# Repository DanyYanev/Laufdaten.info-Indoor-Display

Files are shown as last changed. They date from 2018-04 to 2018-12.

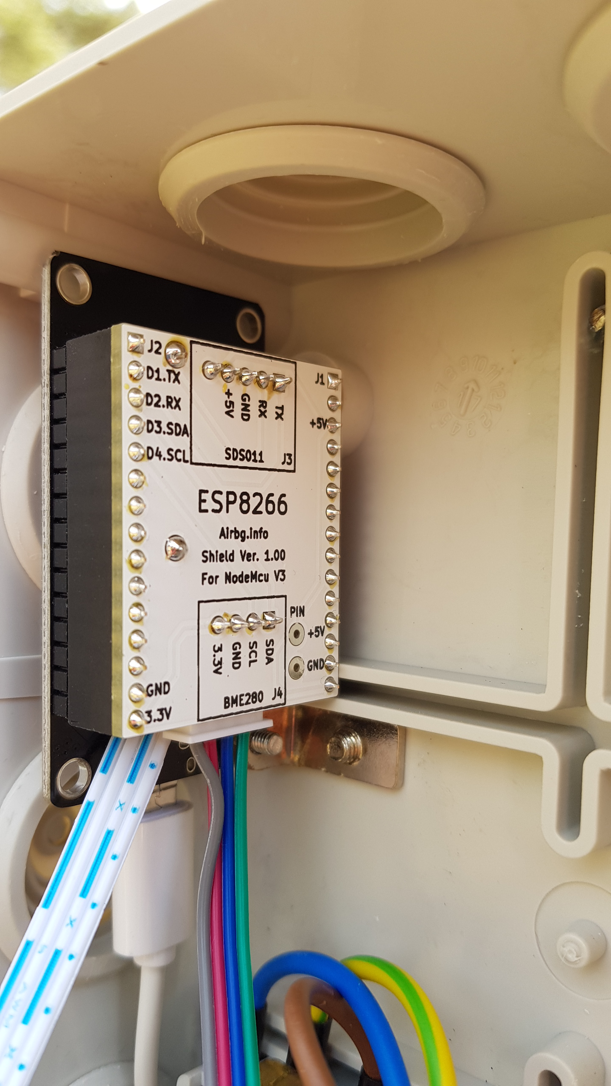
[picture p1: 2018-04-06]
shields/Outdoor Sensor Shield/Pictures/20180310_093059.jpg

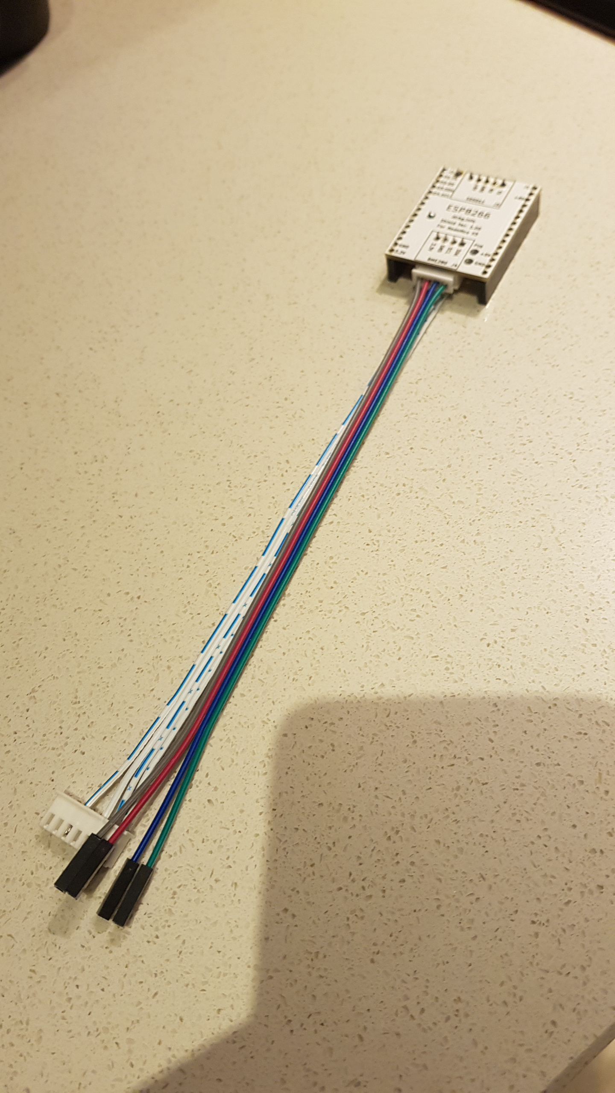
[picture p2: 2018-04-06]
shields/Outdoor Sensor Shield/Pictures/20180309_204822.jpg

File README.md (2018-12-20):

# Laufdaten.info Dust Sensor Indoor Display
Add-on indoor display for your [**laufdaten dust sensor**](https://luftdaten.info/en/home-en/)

If you are contributing to the [**luftdaten.info**](https://luftdaten.info/en/home-en/) project you can build your own indoor weather station and fetch the data off your outdoor sensor.
# How it works
Outside sensor sends information to the Laufdaten servers and to the indoor controller API that displays it on display by your choice. The display controller is connected to your local network with static IP configured from the .ino file (default 192.168.0.50).
The same IP Address you have to add in the outside sensor to send data to the indoor display controller. (More on that in the Configuration Tab) 

*Screenshots from 2.8"(background actually is black)*
allpages

# Getting Started
You will need:
  - Working [Laufdaten dust sensor](https://luftdaten.info/en/construction-manual/) **with BME 280 and SDS011**
  - *Another* NodeMCU v3 ESP8266 or ESP-12E
  - *Another* BME 280
  - A display
    - OLED 0.96" I2C interface
    - OLED 1.3" I2C interface
    - LCD TFT 1.44" SPI interface
    - LCD TFT 2.8"  SPI interface with touch
    - LCD TFT 2.8"  SPI interface without touch
    
## Installing
  ##### Setting up the arduino IDE
  - Install the [Arduino IDE](https://www.arduino.cc/en/Main/Software)
  - Add ESP8266 Libraries
    To begin, we’ll need to update the board manager with a custom URL. Open up Arduino, then go to the Preferences (File > Preferences).       Then, towards the bottom of the window, copy this URL into the “Additional Board Manager URLs” text box:

     > http://arduino.esp8266.com/stable/package_esp8266com_index.json
   - Install the following libraries
      - [WifiManager by Ken Taylor](https://github.com/kentaylor/WiFiManager)
      - [Adafruit Sensors](https://github.com/adafruit/Adafruit_Sensor)
      - [Adafruit BME280](https://github.com/adafruit/Adafruit_BME280_Library)
      - LCD
        - [TFT_eSPI by Bodmer](https://github.com/Bodmer/TFT_eSPI)
      - OLED
        - [Driver library for the SSD1306 and SH1106 OLED by ThingPulse](https://github.com/ThingPulse/esp8266-oled-ssd1306)
        
  ##### Connect the hardware for Oled and LCD 1.44"
  - BME280 (I2C)
    - SDA -> D1
    - SDL -> D2
  - OLED (I2C)
    - SDA -> D1
    - SDL -> D2
  - LCD (SPI)
    - TFT_CS -> D8
    - TFT_DC -> D0
    - TFT_RST -> Reset pin
    - TFT_SCL -> D5
    - TFT_SDA -> D7
    - TFT_LED -> +3.3v
    - Make the appropriate changes to User_Setup.h in Bodmer library (by default on Windowns located in Documents/Arduino/libraries/TFT-eSPI/) according to your display. The User_Setup.h file is very well documented.
    - You can find ready User_Setup.h in code folders. For 1.44 if you have screen offset choose different board.
            
  - Buttons (Pin to GND)
    - D6 (Display page changing)
    - D3 (Configuration Mode -Onboard flash button)
  - You can look also schematic pdf in shields folder
  
  ##### Connect the hardware for LCD 2.80"
  - See schematic pdf in shields folder
  
##### Configure the Indoor Display Conroller
  - After uploading the code the controller will run in Configuration Mode automatically. To manually put the controller in config mode use the flash button. 
  - The device tries to connect to the configured WLAN access point. If this does not work, the controller opens an access point with the name "ESP *id*". The ID referes to the ChipID (ex. ESP12345). Connect to the new network, wait a moment until the connection is made. Sometimes it take multiple attempts.
  - Configure using browser
    - Open your browser and type in http://192.168.4.1/. You see the menu site, choose “Configure” and input your credentional.
    - After saving the desired configuration click on **EXIT PORTAL**! Else the configuration won't be saved.
  **OR**
  - Configure using android application. Special thanks to Keneth Taylor.
    - Download the [ESP Connect app](https://play.google.com/store/apps/details?id=au.com.umranium.espconnect) and follow the steps.
  - Oled version is without WiFi menager and you must add wifi SSID and Password in the code.  
  
##### Configure the OutsideSensor
  - Find laufdatens sensor IP Address.
  - Go to its IP Address (ex. 192.168.0.112)
  - Click on Configuration
  - Add the static IP of the indoor display controller 192.168.0.50, (standart router settings from 192.168.0.2 through 192.168.0.99 are not used for DHCP).
  - The path and the port as shown below.
outdoor sensor settings

## Shields
  - Kicad and Gerber files are in shields folder.
    - Indoor display
      - Oled 0.96 (Tested)
      - LCD 1.44  (Tested)
      - LCD 2.80  (ESP-12E tested)
      - LCD 2.80  (NodeMCU not tested)
    - Outdoor sensor for better connection between sensors and ESP.

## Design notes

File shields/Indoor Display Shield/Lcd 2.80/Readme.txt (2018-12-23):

Buttons on D2 and D6 are not used with touchscreen.
Led on D4 duplicate led on ESP.
PCB can be use with another sensors for air quality BME680 or CCS811.

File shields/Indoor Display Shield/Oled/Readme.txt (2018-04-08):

This shield is for Oled 0.96 and few sensors 
(BME280,BME680 and SDS011).
For this code use only BME280 and 2 buttons.

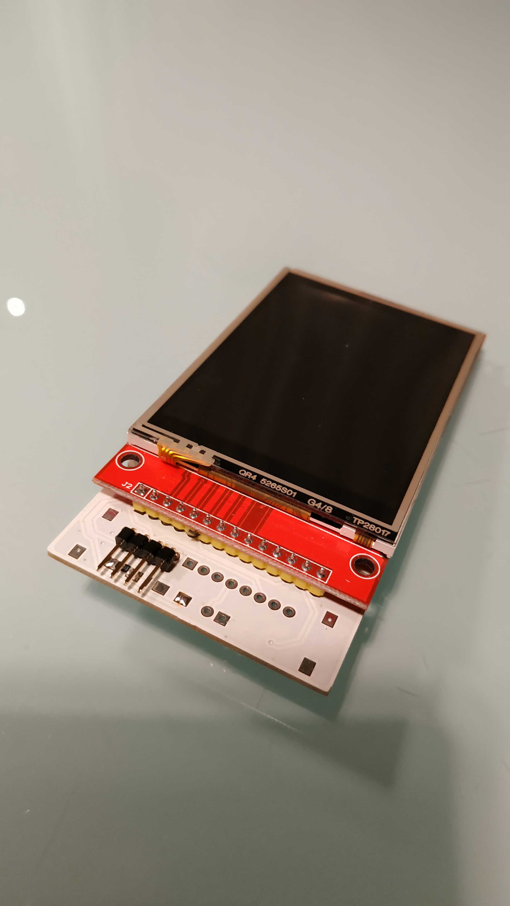
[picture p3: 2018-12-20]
shields/Indoor Display Shield/Lcd 2.80/Pictures ESP-12E/Touch screen1.jpg

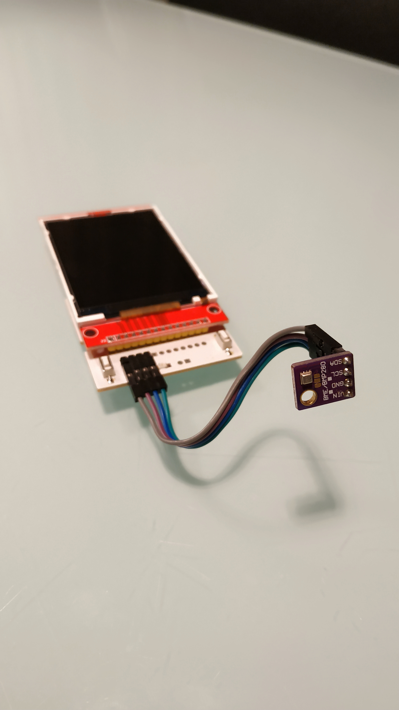
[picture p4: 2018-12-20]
shields/Indoor Display Shield/Lcd 2.80/Pictures ESP-12E/Two buttons4.jpg

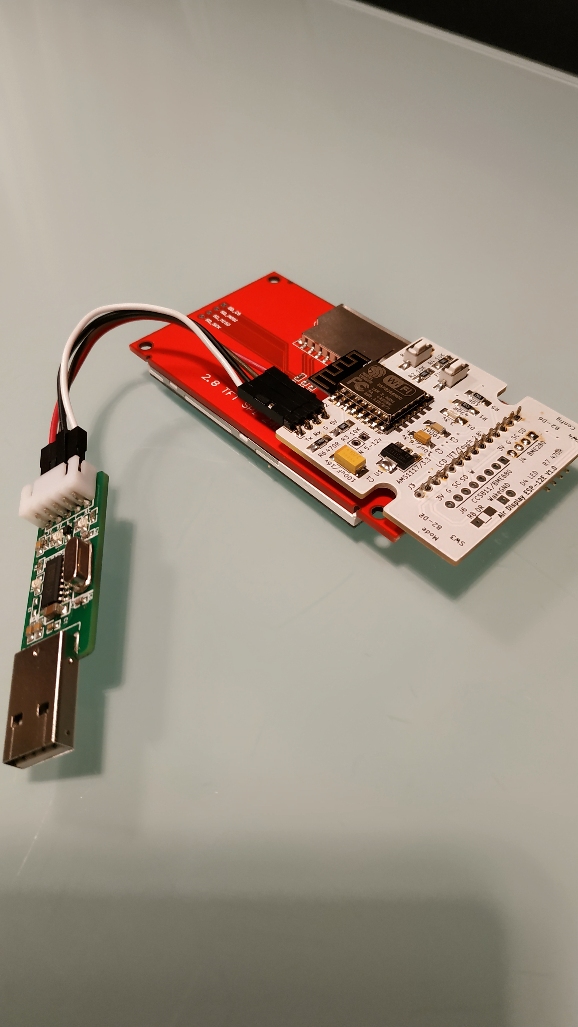
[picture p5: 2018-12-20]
shields/Indoor Display Shield/Lcd 2.80/Pictures ESP-12E/Touch screen3.jpg

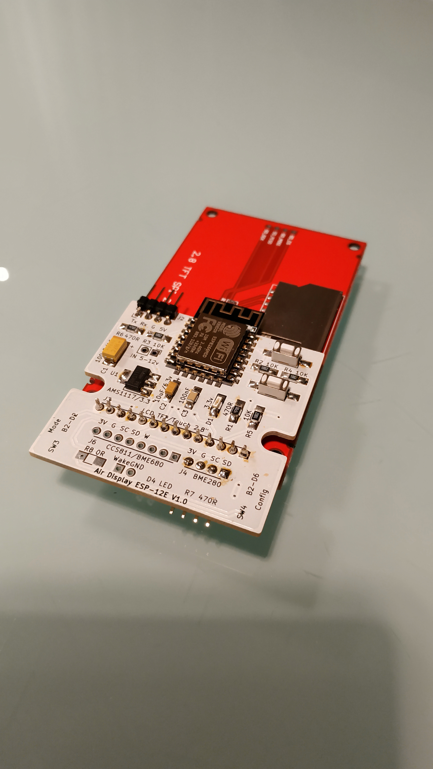
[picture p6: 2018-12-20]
shields/Indoor Display Shield/Lcd 2.80/Pictures ESP-12E/Touch screen2.jpg

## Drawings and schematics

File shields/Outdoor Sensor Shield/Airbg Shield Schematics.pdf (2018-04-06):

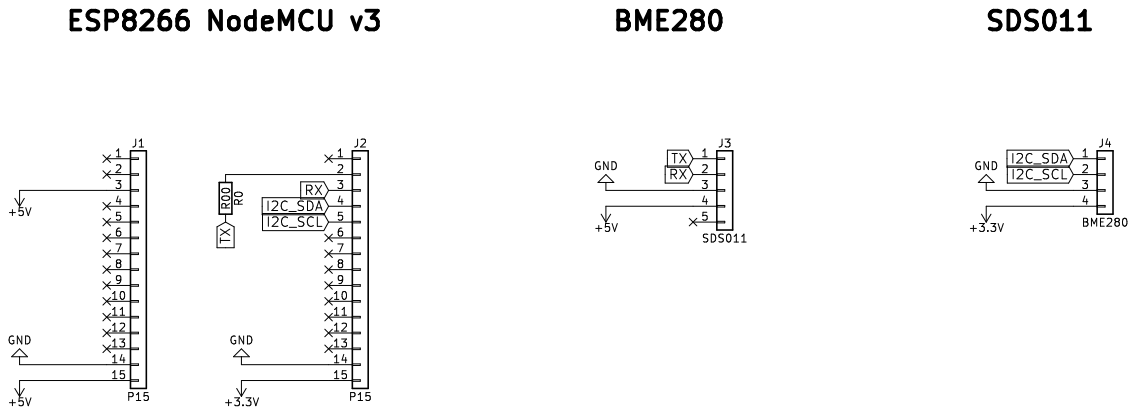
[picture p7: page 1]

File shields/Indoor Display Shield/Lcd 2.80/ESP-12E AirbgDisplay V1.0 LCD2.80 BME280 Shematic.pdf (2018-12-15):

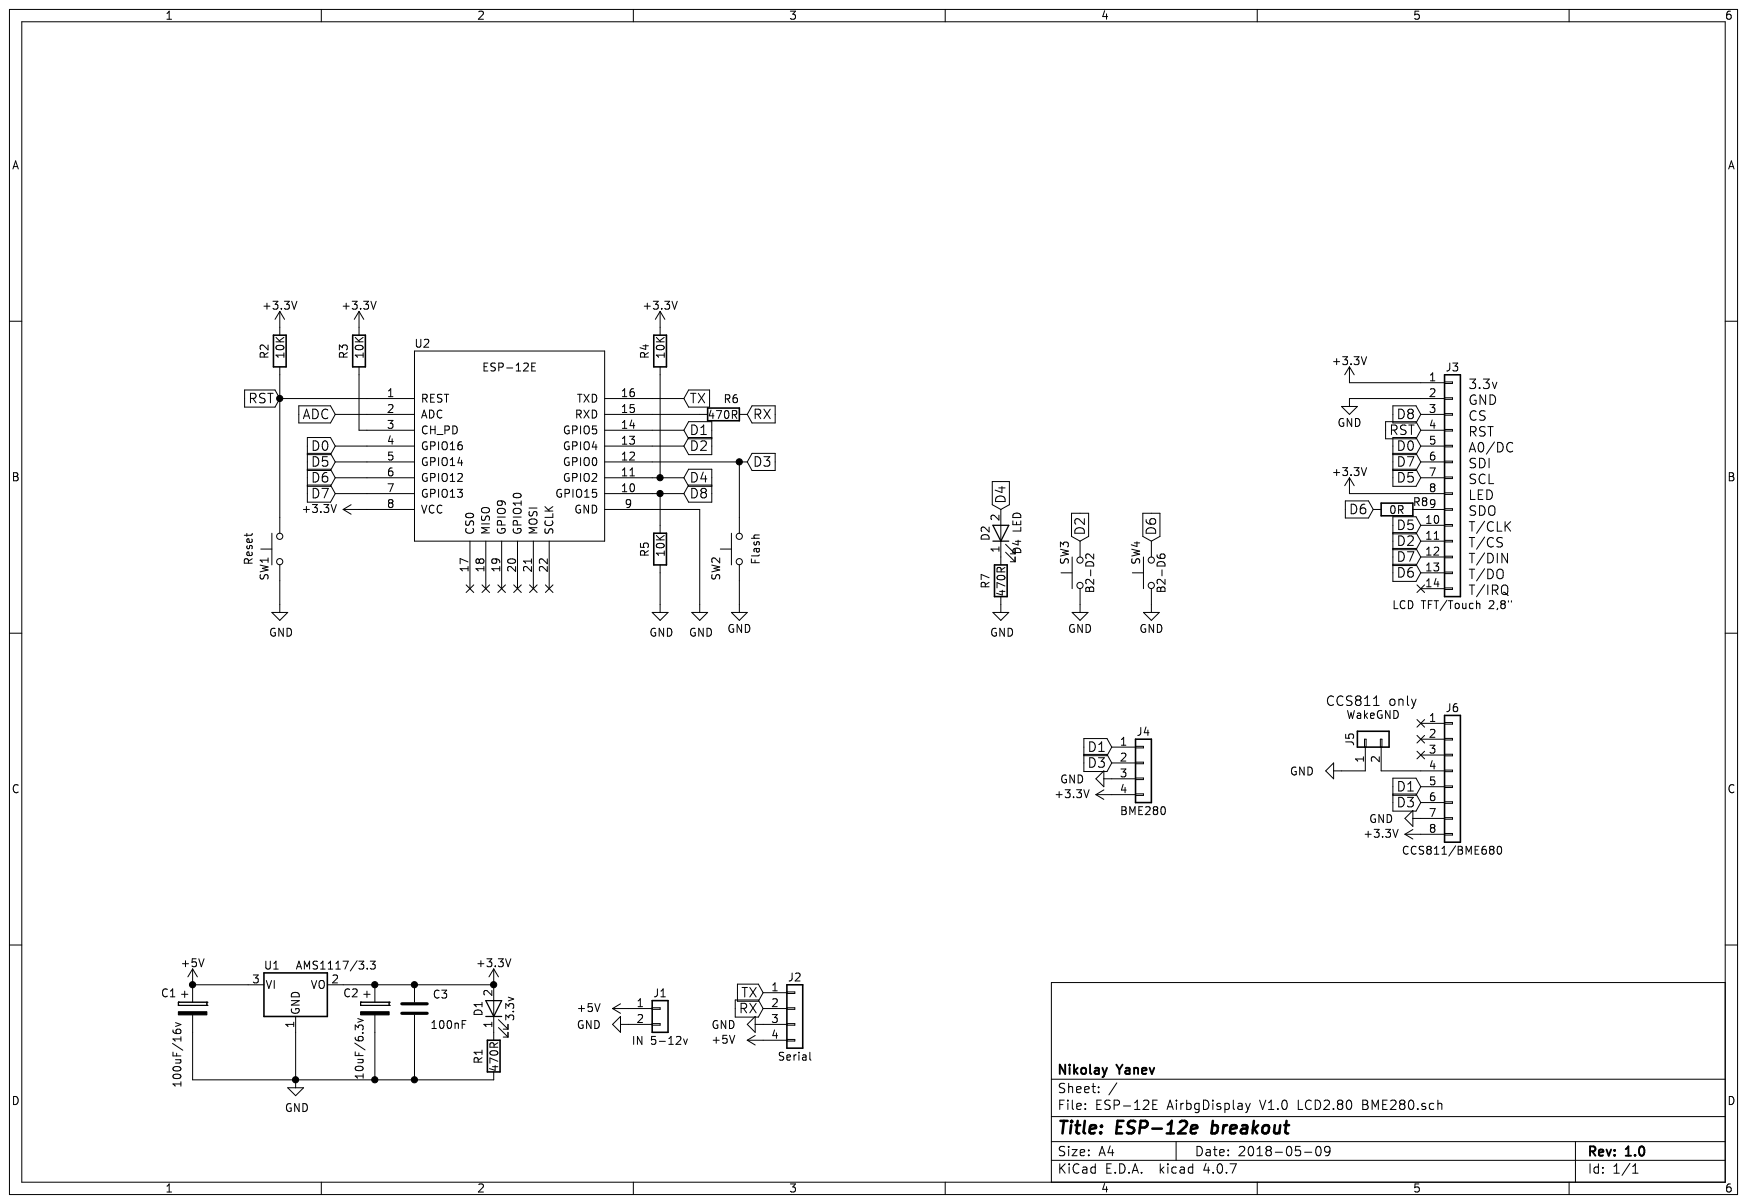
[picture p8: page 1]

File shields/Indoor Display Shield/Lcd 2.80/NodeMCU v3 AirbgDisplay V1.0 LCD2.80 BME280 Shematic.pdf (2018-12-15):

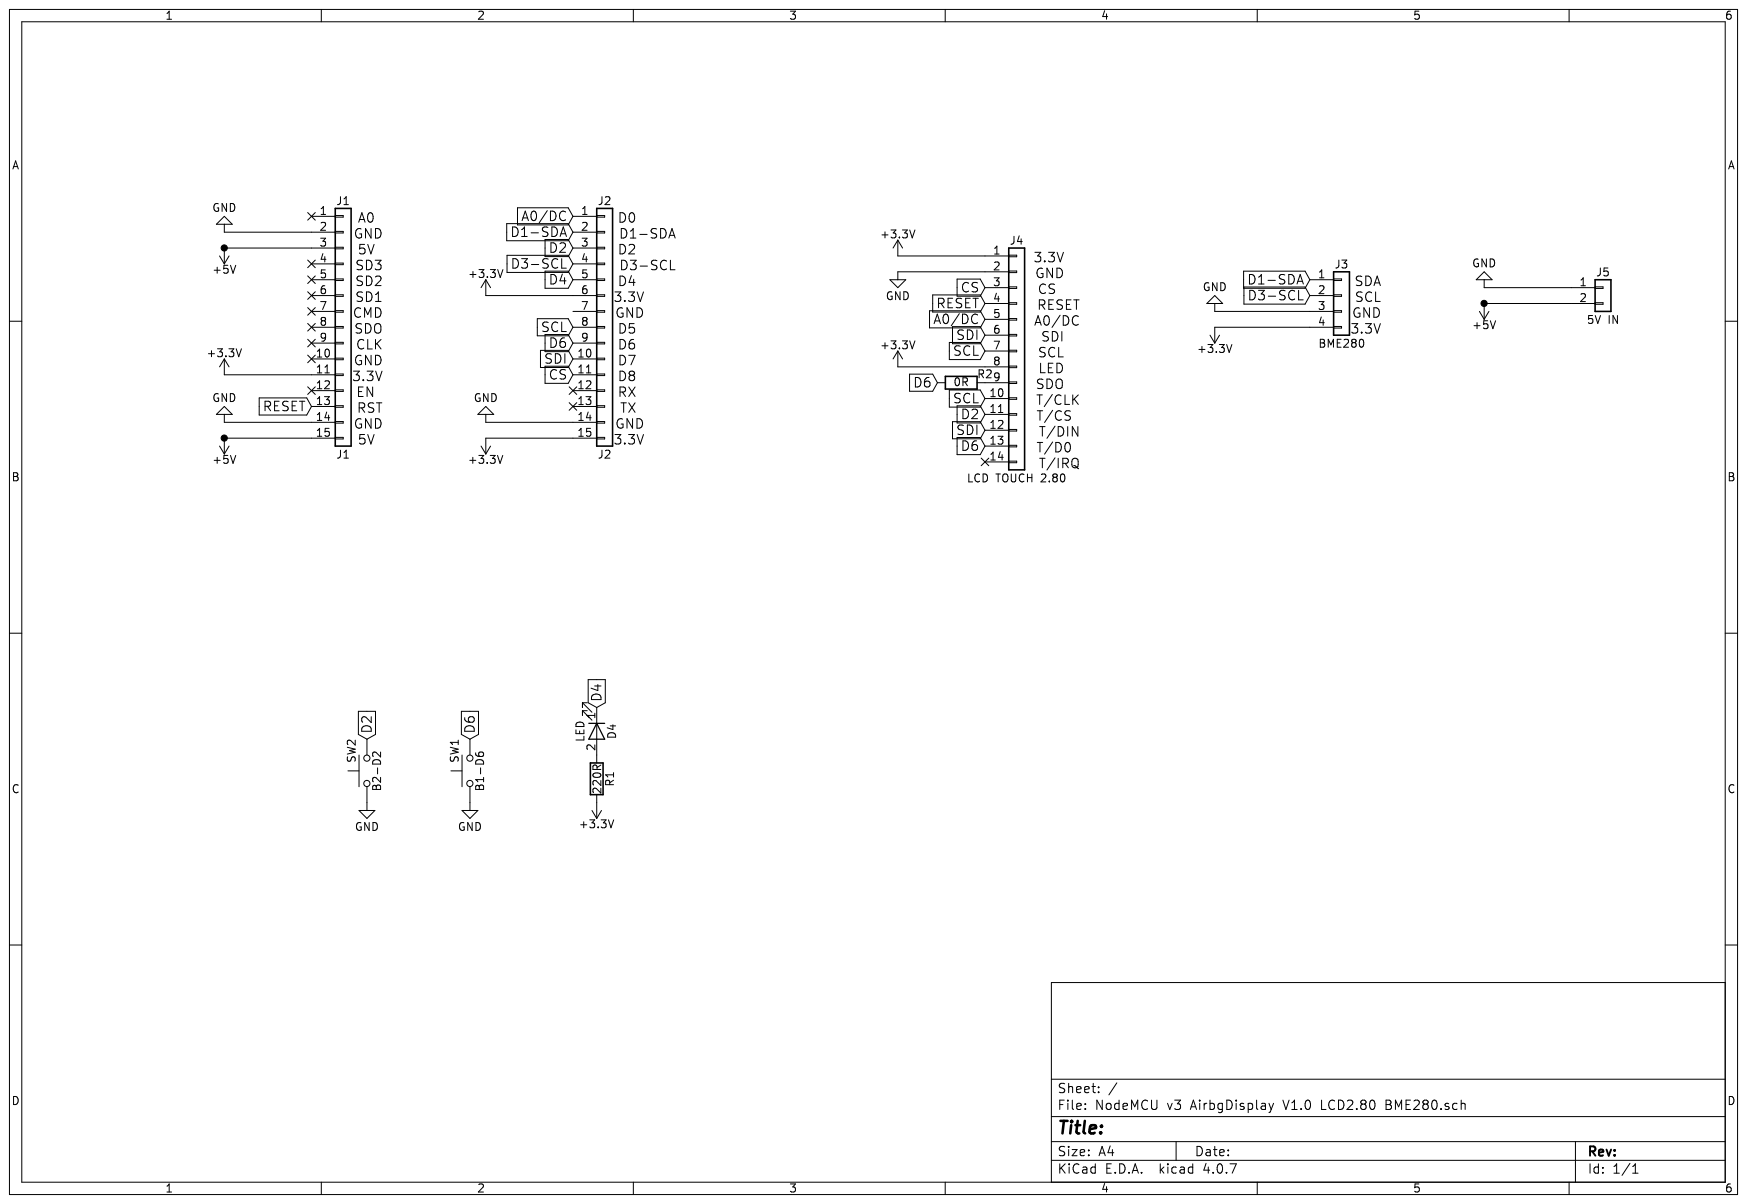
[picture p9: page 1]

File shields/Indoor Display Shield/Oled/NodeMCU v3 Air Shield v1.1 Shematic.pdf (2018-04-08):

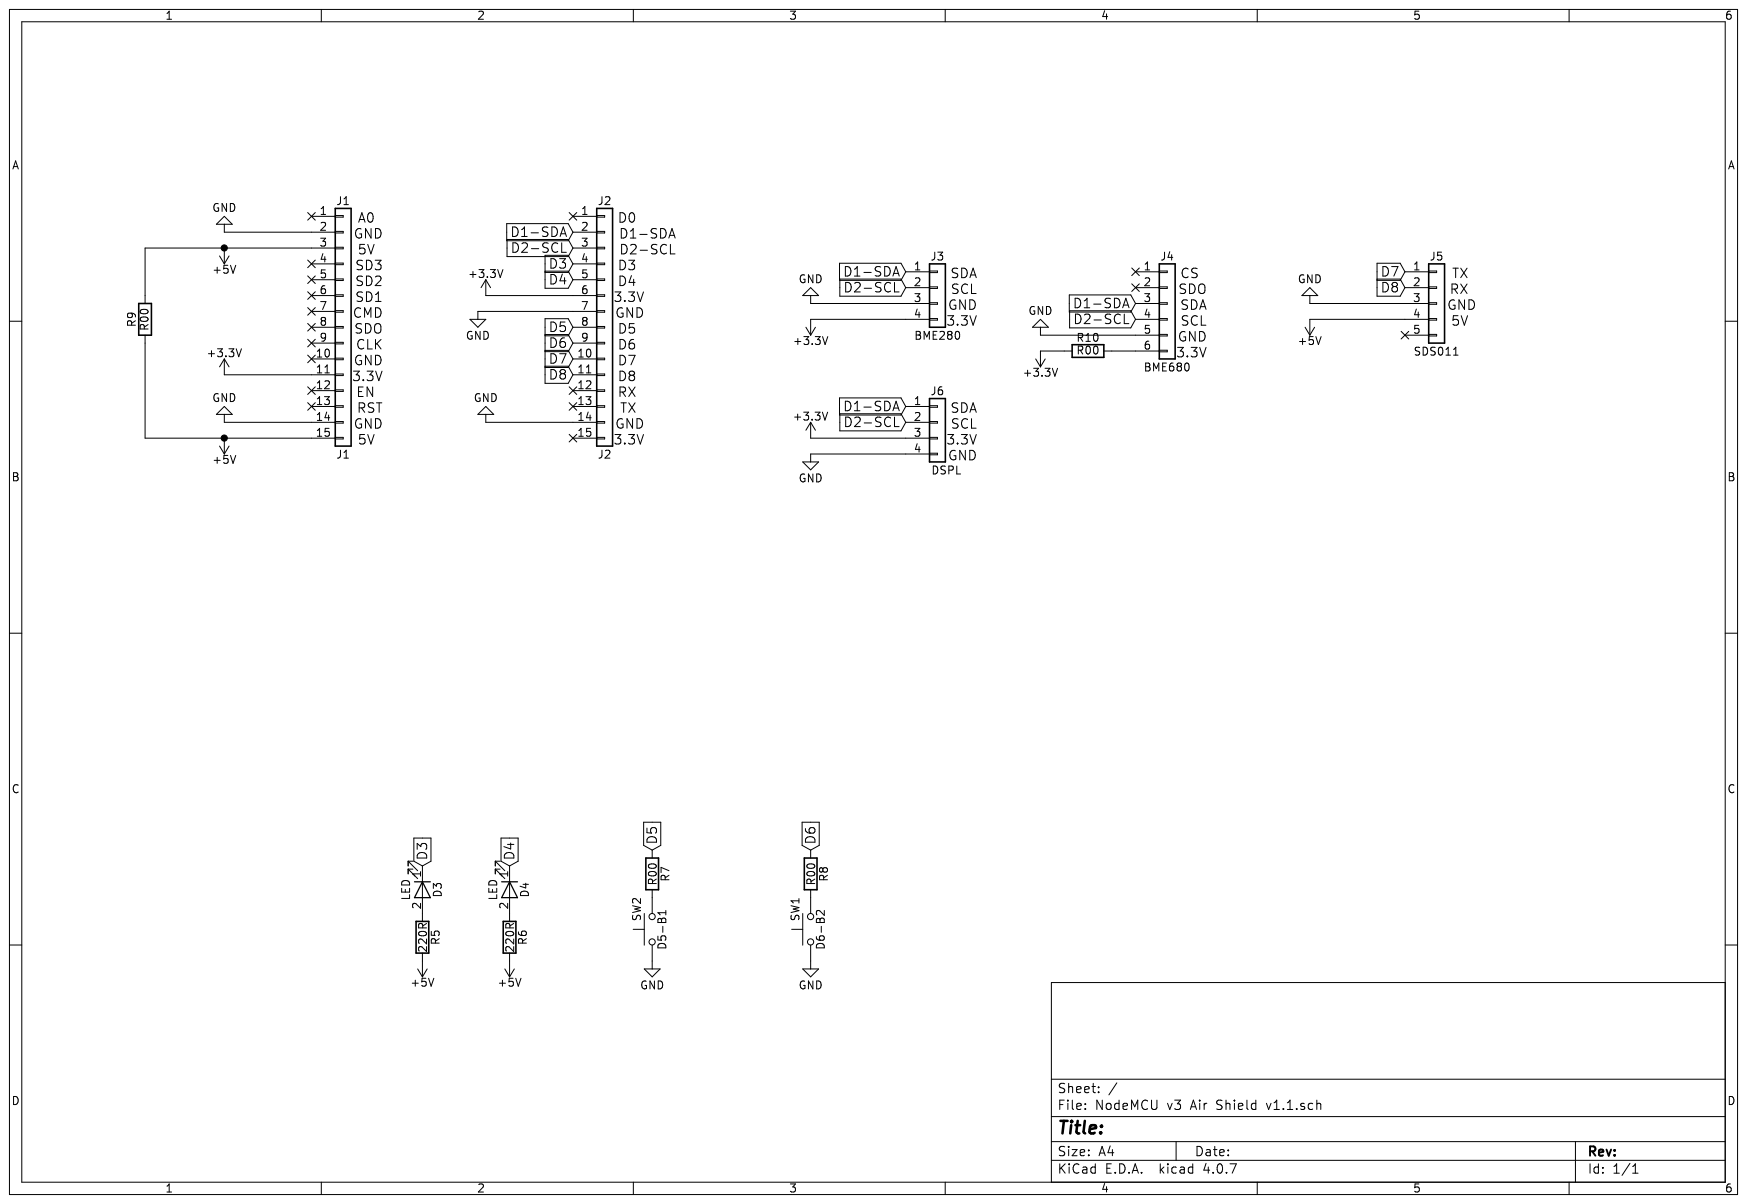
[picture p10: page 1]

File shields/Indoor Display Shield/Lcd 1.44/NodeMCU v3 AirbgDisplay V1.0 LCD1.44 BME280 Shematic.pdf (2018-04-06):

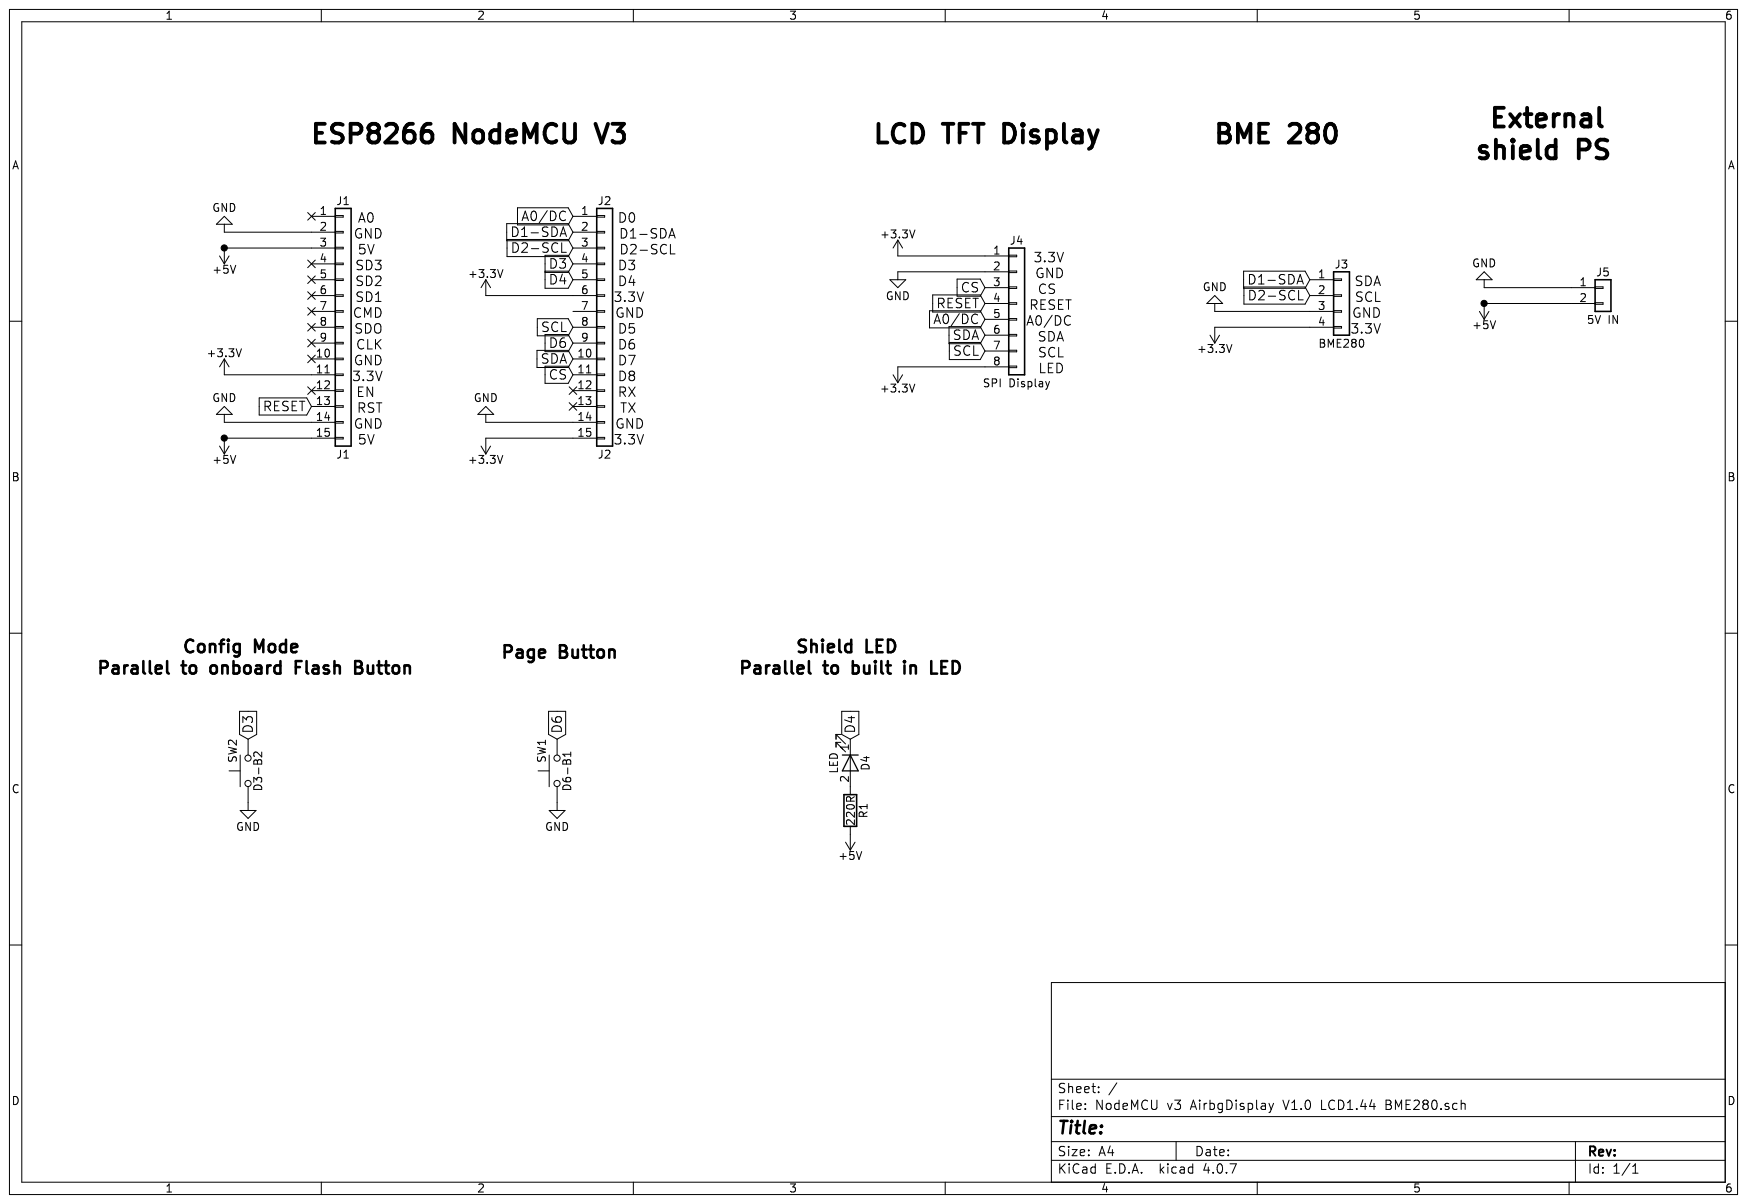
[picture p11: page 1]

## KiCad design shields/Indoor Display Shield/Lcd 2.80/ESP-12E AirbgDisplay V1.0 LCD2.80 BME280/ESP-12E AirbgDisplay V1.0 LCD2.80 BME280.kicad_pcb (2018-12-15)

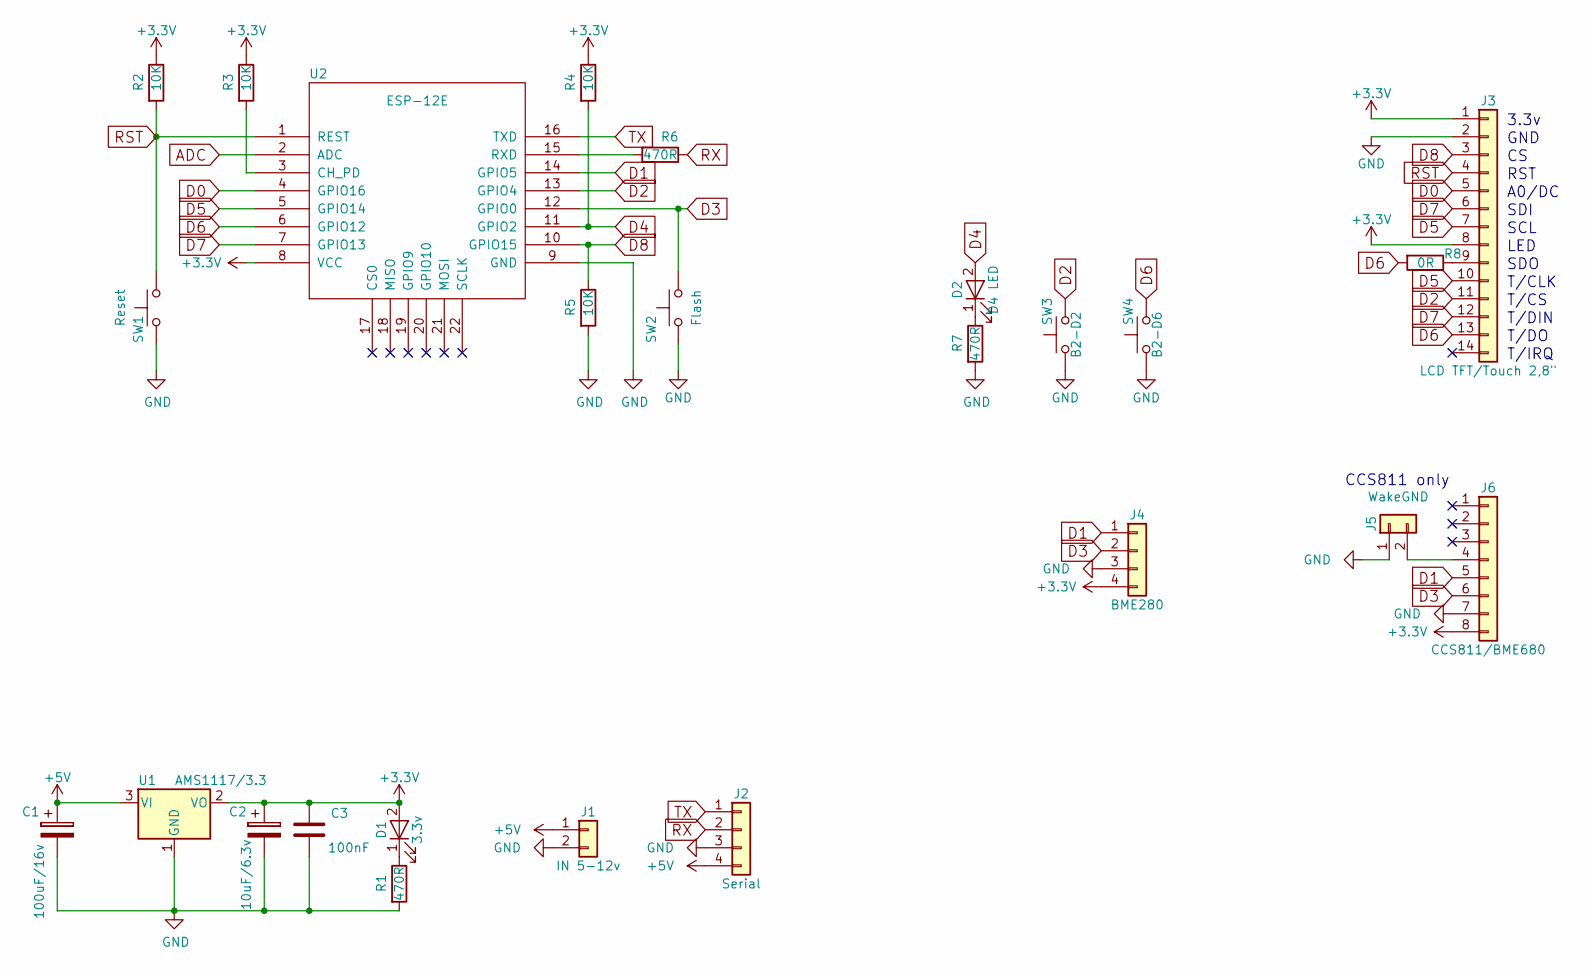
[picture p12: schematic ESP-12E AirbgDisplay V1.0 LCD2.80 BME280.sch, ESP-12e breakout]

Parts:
C1: 100uF/16v; C_1812_HandSoldering
C2: 10uF/6.3v; C_1206_HandSoldering
C3: 100nF; C_1206_HandSoldering
D1: 3.3v; LED_1206_HandSoldering
D2: D4 LED; LED_1206_HandSoldering
J1: IN 5-12v; Pin_Header_Straight_1x02_Pitch2.54mm
J2: Serial; Pin_Header_Angled_1x04_Pitch2.54mm
J3: LCD TFT/Touch 2,8\"; Pin_Header_Straight_1x14_Pitch2.54mm
J4: BME280; Pin_Header_Straight_1x04_Pitch2.54mm
J5: WakeGND; Pin_Header_Straight_1x02_Pitch2.54mm
J6: CCS811/BME680; Pin_Header_Straight_1x08_Pitch2.54mm
R1, R6, R7: 470R; R_1206_HandSoldering
R2, R3, R4, R5: 10K; R_1206_HandSoldering
R8: 0R; R_1206_HandSoldering
SW1: Reset; SW_SPST_FSMSM
SW2: Flash; SW_SPST_FSMSM
SW3: B2-D2; SW_SPST_FSMSM
SW4: B2-D6; SW_SPST_FSMSM
U1: AMS1117/3.3; SOT-223-3_TabPin2
U2: ESP-12E; ESP-12E_SMD

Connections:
+3V3: C2.1, C3.1, D1.2 (A), J3.1, J3.8, J4.4, J6.8, R2.1, R3.1, R4.1, U1.2 (VO), U2.8 (VCC)
+5V: C1.1, J1.1, J2.4, U1.3 (VI)
ADC: U2.2 (ADC)
D0: J3.5, U2.4 (GPIO16)
D1: J4.1, J6.5, U2.14 (GPIO5)
D2: J3.11, SW3.2, U2.13 (GPIO4)
D3: J4.2, J6.6, SW2.2, U2.12 (GPIO0)
D4: D2.2 (A), R4.2, U2.11 (GPIO2)
D5: J3.7, J3.10, U2.5 (GPIO14)
D6: J3.13, R8.2, SW4.2, U2.6 (GPIO12)
D7: J3.6, J3.12, U2.7 (GPIO13)
D8: J3.3, R5.1, U2.10 (GPIO15)
GND: C1.2, C2.2, C3.2, J1.2, J2.3, J3.2, J4.3, J5.1, J6.7, R1.2, R5.2, R7.2, SW1.1, SW2.1, SW3.1, SW4.1, U1.1 (GND), U2.9 (GND)
unnamed: D1.1 (K), R1.1
unnamed: D2.1 (K), R7.1
unnamed: J3.9, R8.1
unnamed: J5.2, J6.4
unnamed: R3.2, U2.3 (CH_PD)
unnamed: R6.2, U2.15 (RXD)
RST: J3.4, R2.2, SW1.2, U2.1 (REST)
RX: J2.2, R6.1
TX: J2.1, U2.16 (TXD)

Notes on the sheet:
3.3v
GND
RST
A0/DC
SDI
SCL
LED
SDO
T/CLK
T/CS
T/DIN
T/DO
T/IRQ
CCS811 only

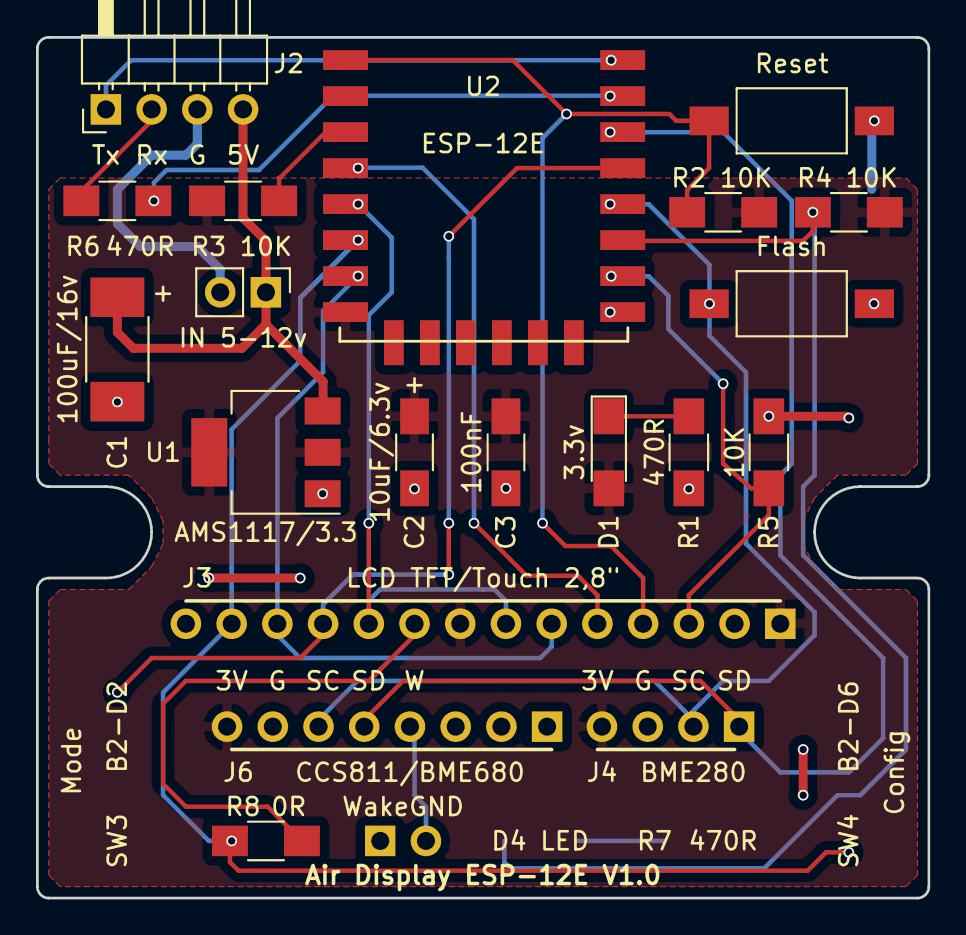
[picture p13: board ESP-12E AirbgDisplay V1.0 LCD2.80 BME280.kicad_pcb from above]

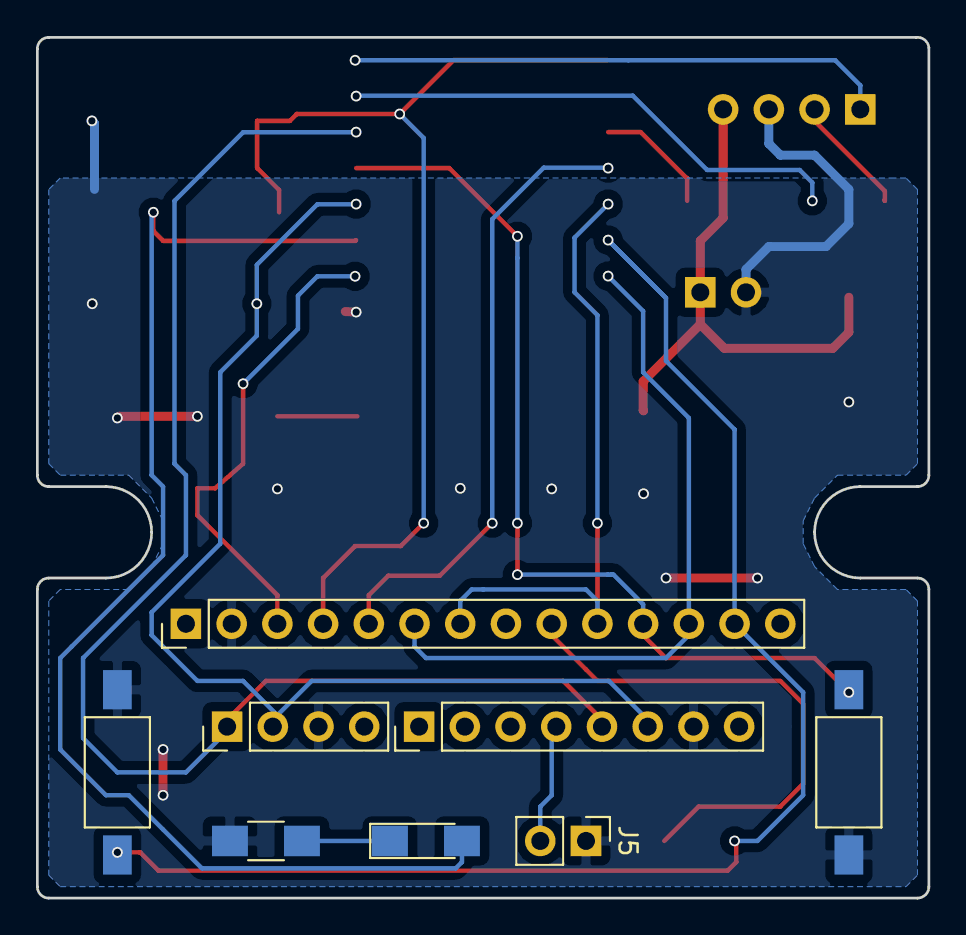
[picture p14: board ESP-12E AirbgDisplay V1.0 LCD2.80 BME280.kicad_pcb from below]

Board: 2 copper layers, 49.5 x 47.8 mm, 25 parts (8 on the bottom side), 21 nets.

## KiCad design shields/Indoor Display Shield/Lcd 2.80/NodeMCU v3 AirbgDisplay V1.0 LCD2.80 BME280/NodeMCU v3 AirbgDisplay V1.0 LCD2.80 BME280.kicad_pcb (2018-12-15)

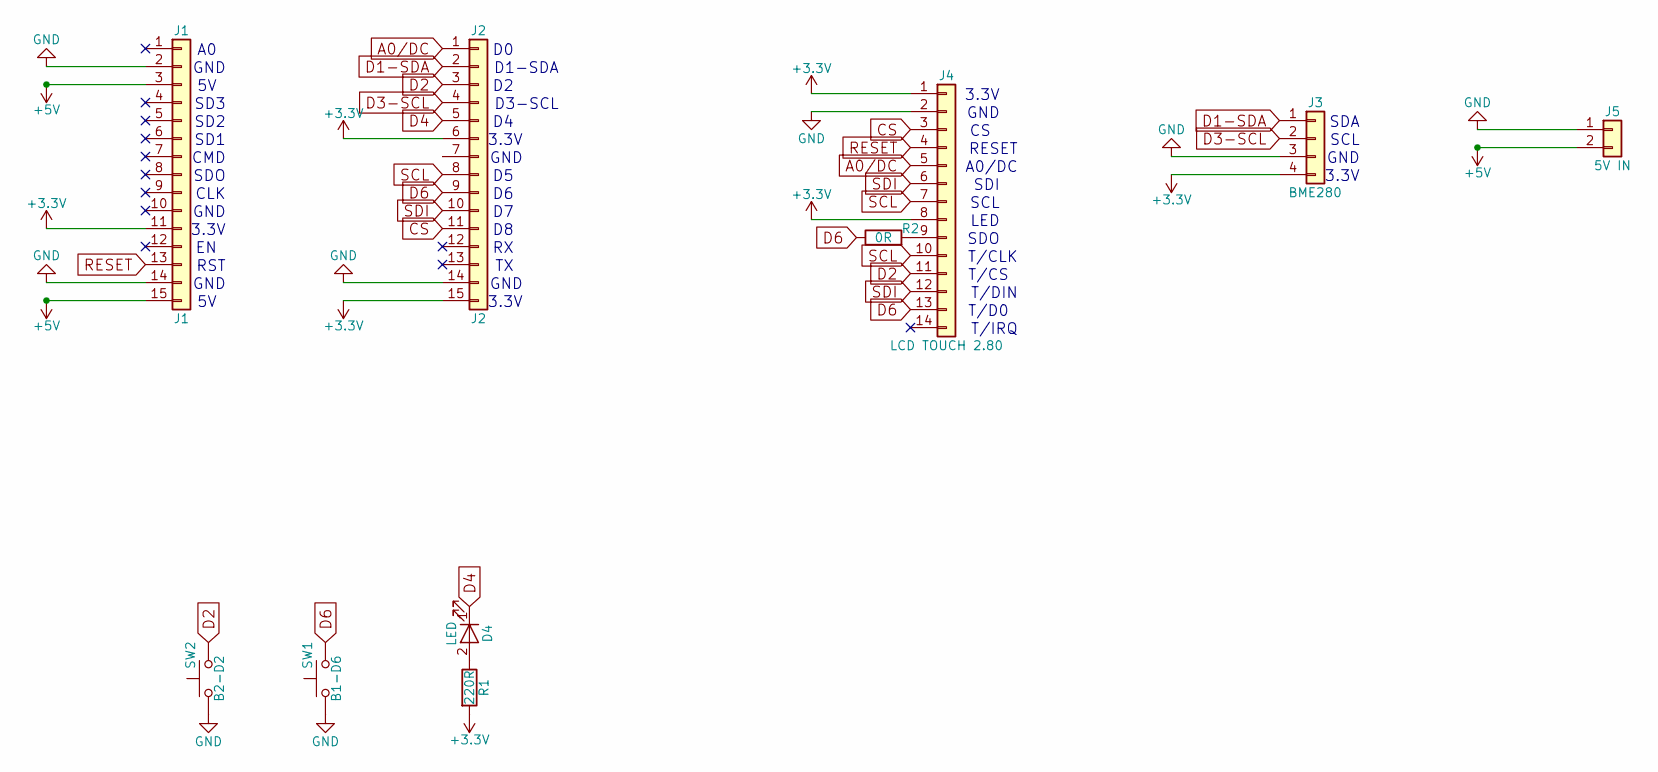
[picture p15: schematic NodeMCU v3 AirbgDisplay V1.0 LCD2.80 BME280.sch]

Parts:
D4: LED; LED_1206_HandSoldering
J1: J1; Pin_Header_Straight_1x15_Pitch2.54mm
J2: J2; Pin_Header_Straight_1x15_Pitch2.54mm
J3: BME280; Pin_Header_Straight_1x04_Pitch2.54mm
J4: LCD TOUCH 2.80; Pin_Header_Straight_1x14_Pitch2.54mm
J5: 5V IN; JST_XH_S02B-XH-A_02x2.50mm_Angled
R1: 220R; R_1206_HandSoldering
R2: 0R; R_1206_HandSoldering
SW1: B1-D6; SW_PUSH_6mm_h5mm
SW2: B2-D2; SW_PUSH_6mm_h5mm

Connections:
+3V3: J1.11, J2.6, J2.15, J3.4, J4.1, J4.8, R1.2
+5V: J1.3, J1.15, J5.2
A0/DC: J2.1, J4.5
CS: J2.11, J4.3
D1-SDA: J2.2, J3.1
D2: J2.3, J4.11, SW2.2
D3-SCL: J2.4, J3.2
D4: D4.1 (K), J2.5
D6: J2.9, J4.13, R2.1, SW1.2
GND: J1.2, J1.14, J2.14, J3.3, J4.2, J5.1, SW1.1, SW2.1
unnamed: D4.2 (A), R1.1
unnamed: J4.9, R2.2
RESET: J1.13, J4.4
SCL: J2.8, J4.7, J4.10
SDI: J2.10, J4.6, J4.12

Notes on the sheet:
D1-SDA
D3-SCL
3.3V
GND
SCL
SDA
SD1
SD2
SD3
CMD
SDO
CLK
RST
LED
RESET
A0/DC
SDI
T/CLK
T/CS
T/DIN
T/D0
T/IRQ

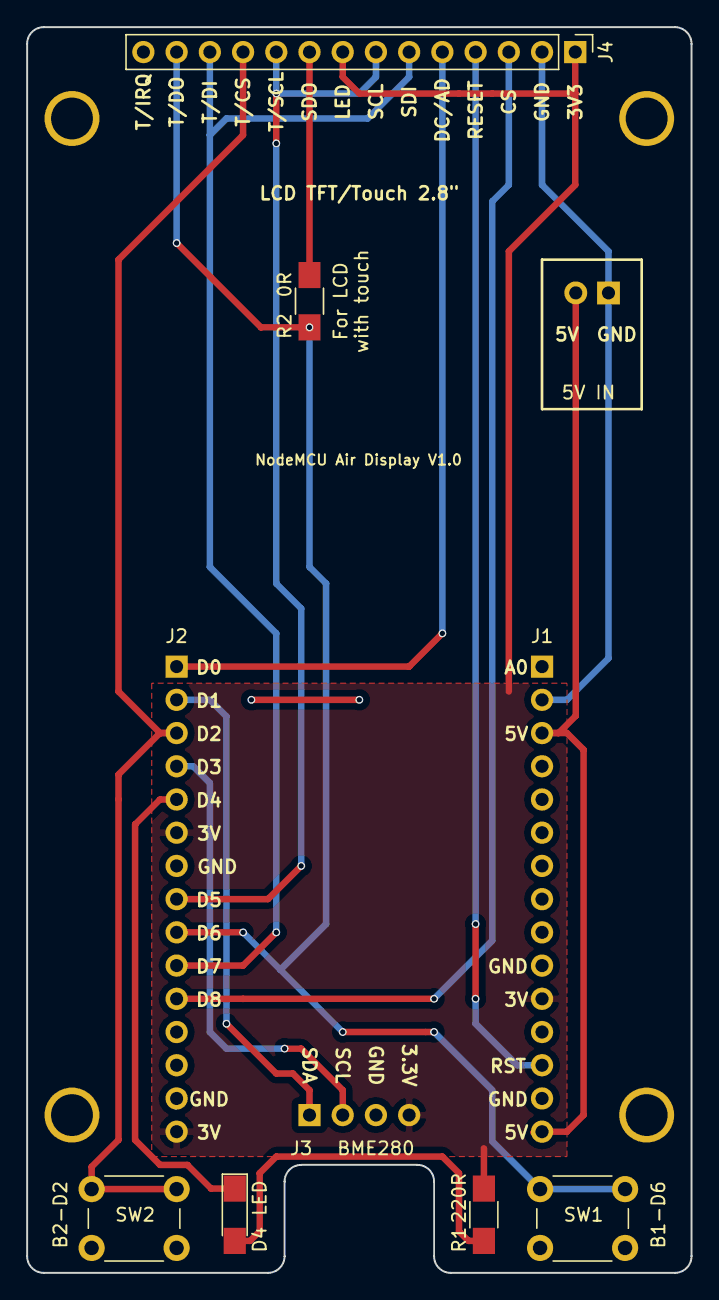
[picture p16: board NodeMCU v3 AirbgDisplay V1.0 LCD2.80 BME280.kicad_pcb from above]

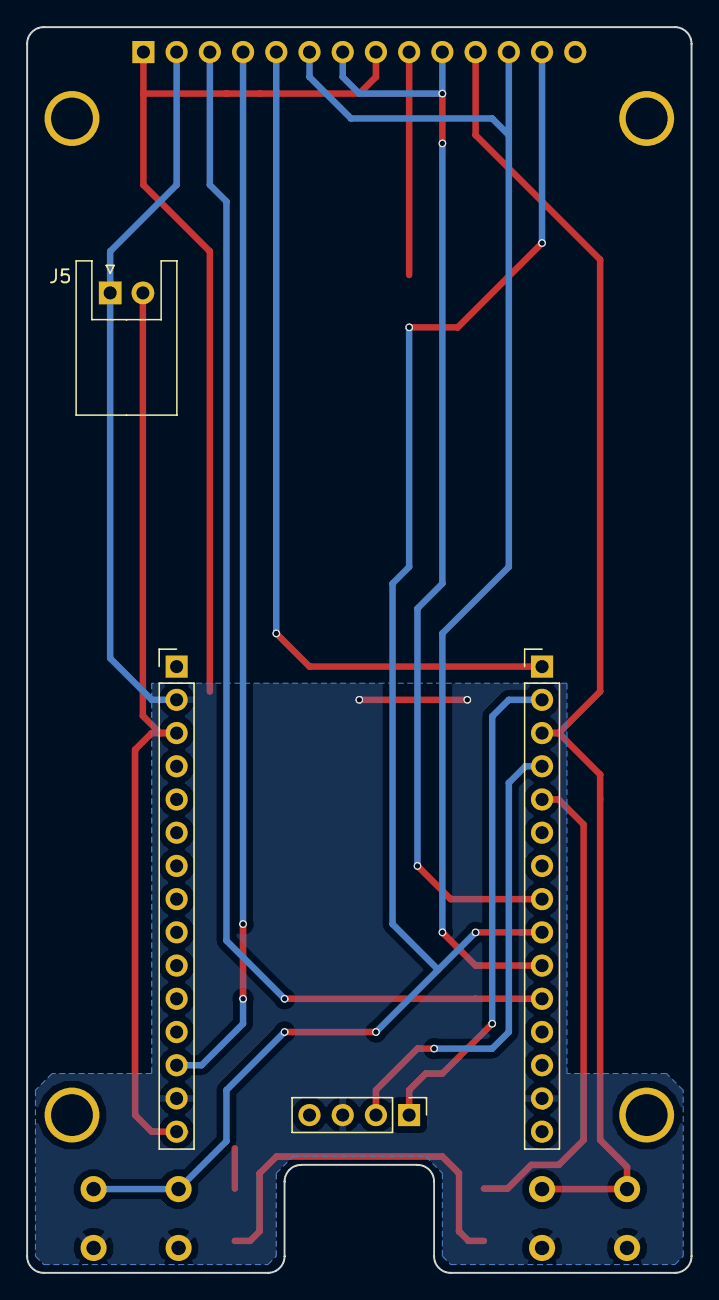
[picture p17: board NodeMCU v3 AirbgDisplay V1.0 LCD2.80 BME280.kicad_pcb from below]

Board: 2 copper layers, 50.8 x 95.2 mm, 14 parts (8 on the bottom side), 15 nets.

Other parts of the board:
3mm, 3mm#2, 3mm#3, 3mm#4: 1; SolderWirePad_single_2mmDrill

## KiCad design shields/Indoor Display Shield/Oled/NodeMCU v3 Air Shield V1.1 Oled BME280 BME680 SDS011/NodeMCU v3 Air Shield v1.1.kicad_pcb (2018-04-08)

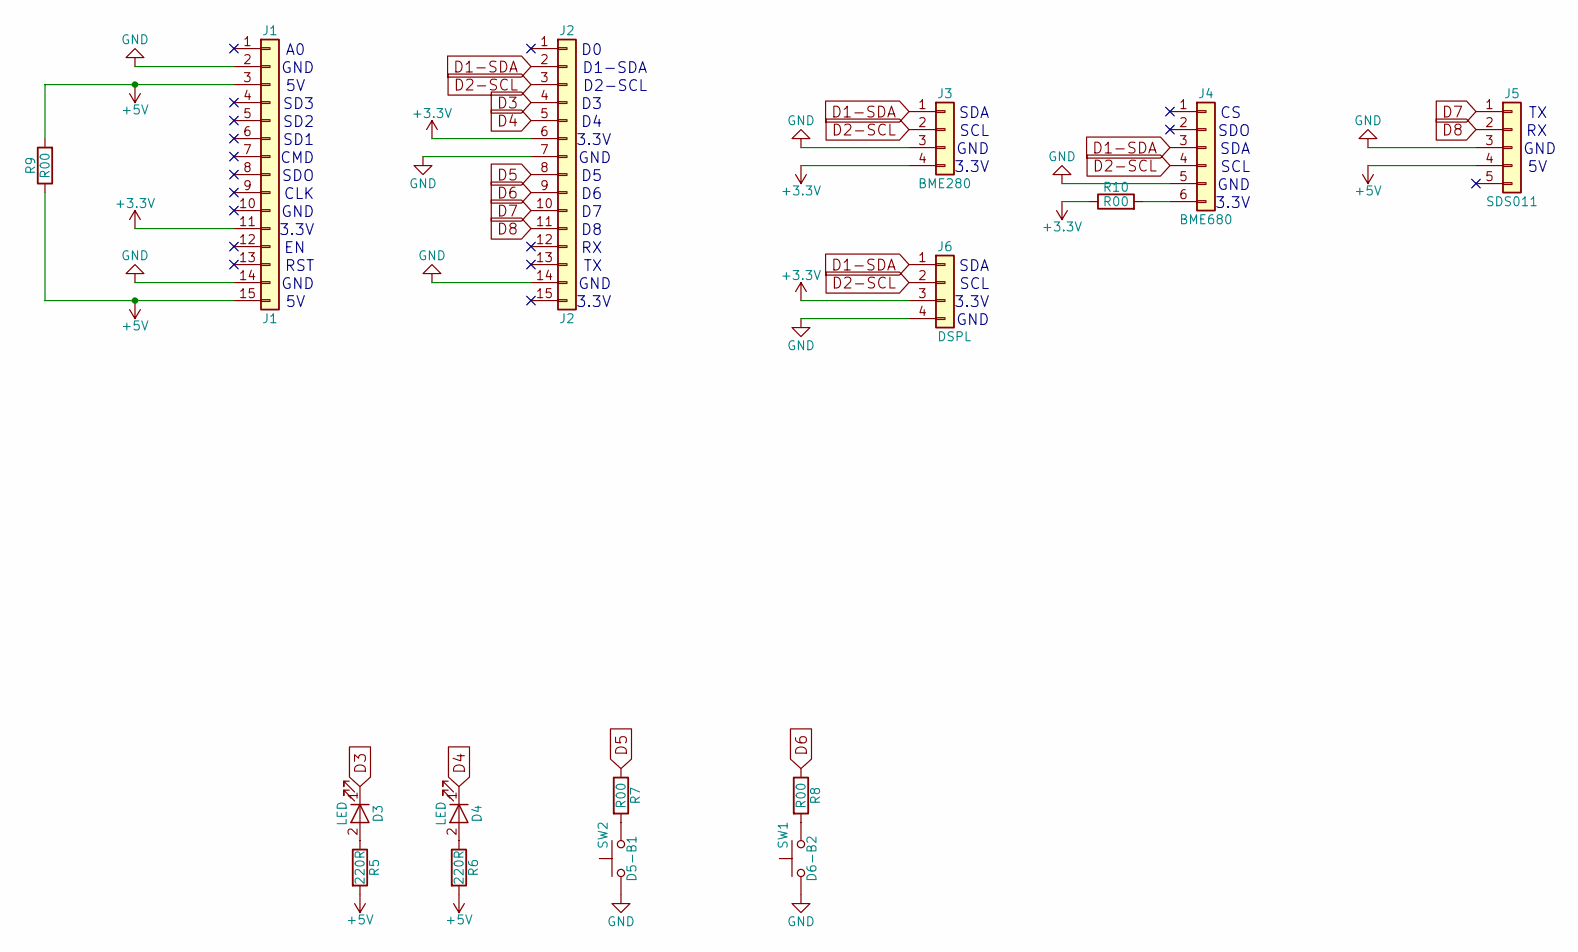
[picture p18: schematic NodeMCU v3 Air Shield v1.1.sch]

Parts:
D3, D4: LED; LED_1206_HandSoldering
J1: J1; Pin_Header_Straight_1x15_Pitch2.54mm
J2: J2; Pin_Header_Straight_1x15_Pitch2.54mm
J3: BME280; Pin_Header_Straight_1x04_Pitch2.54mm
J4: BME680; Pin_Header_Straight_1x06_Pitch2.54mm
J5: SDS011; JST_XH_S05B-XH-A_05x2.50mm_Angled
J6: DSPL; Pin_Header_Straight_1x04_Pitch2.54mm
R5, R6: 220R; R_1206_HandSoldering
R7, R8, R9, R10: R00; WireConnection_1.00mmDrill
SW1: D6-B2; SW_PUSH_6mm
SW2: D5-B1; SW_PUSH_6mm

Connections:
+3V3: J1.11, J2.6, J3.4, J6.3, R10.1
+5V: J1.3, J1.15, J5.4, R5.2, R6.2, R9.1, R9.2; also elsewhere on the board
D1-SDA: J2.2, J3.1, J4.3, J6.1
D2-SCL: J2.3, J3.2, J4.4, J6.2
D3: D3.1 (K), J2.4
D4: D4.1 (K), J2.5
D5: J2.8, R7.1
D6: J2.9, R8.1
D7: J2.10, J5.1
D8: J2.11, J5.2
GND: J1.2, J1.14, J2.7, J2.14, J3.3, J4.5, J5.3, J6.4, SW1.1, SW2.1; also elsewhere on the board
unnamed: D3.2 (A), R5.1
unnamed: D4.2 (A), R6.1
unnamed: J4.6, R10.2
unnamed: R7.2, SW2.2
unnamed: R8.2, SW1.2

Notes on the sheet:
D1-SDA
D2-SCL
3.3V
GND
SCL
SDO
SDA
SD1
SD2
SD3
CMD
CLK
RST

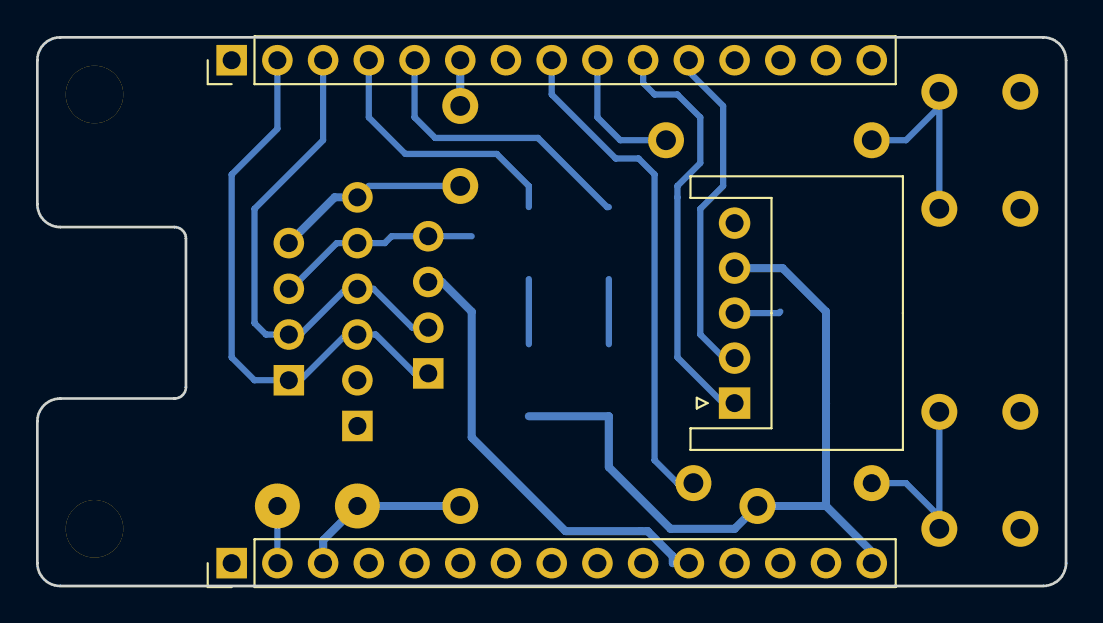
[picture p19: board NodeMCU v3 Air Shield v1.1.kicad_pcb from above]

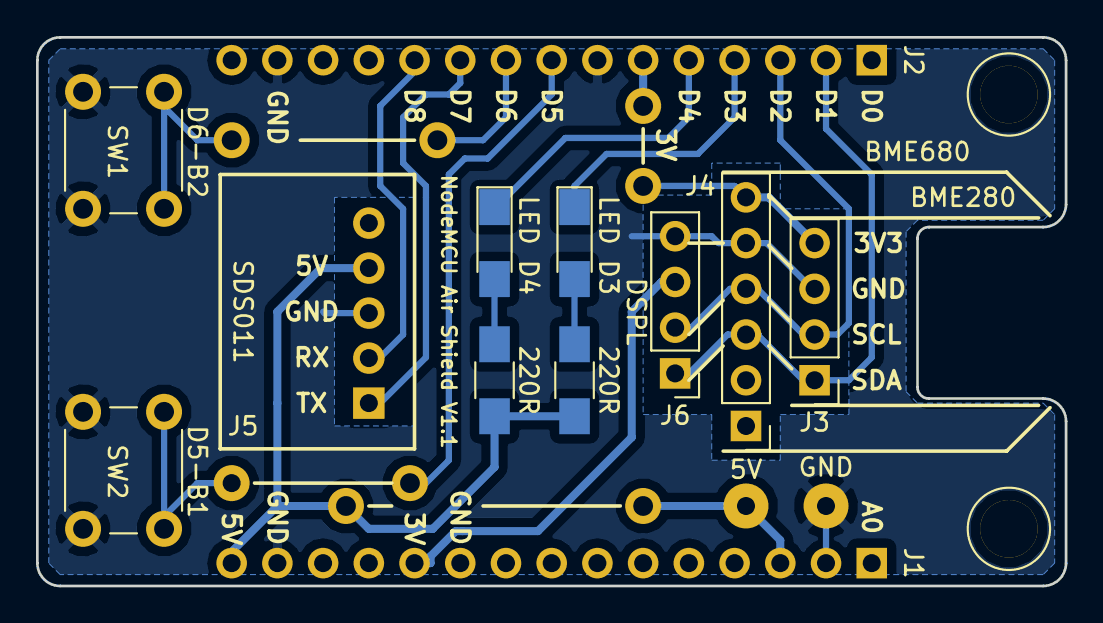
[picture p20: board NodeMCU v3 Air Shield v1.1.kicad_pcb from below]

Board: 2 copper layers, 57.1 x 30.5 mm, 19 parts (13 on the bottom side), 16 nets.

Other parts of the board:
3mm, 3mm#2: 1pin
5V: GND; SolderWirePad_2x_1mmDrill

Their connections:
+5V: 5V.1; also elsewhere on the board
GND: 5V.1; also elsewhere on the board

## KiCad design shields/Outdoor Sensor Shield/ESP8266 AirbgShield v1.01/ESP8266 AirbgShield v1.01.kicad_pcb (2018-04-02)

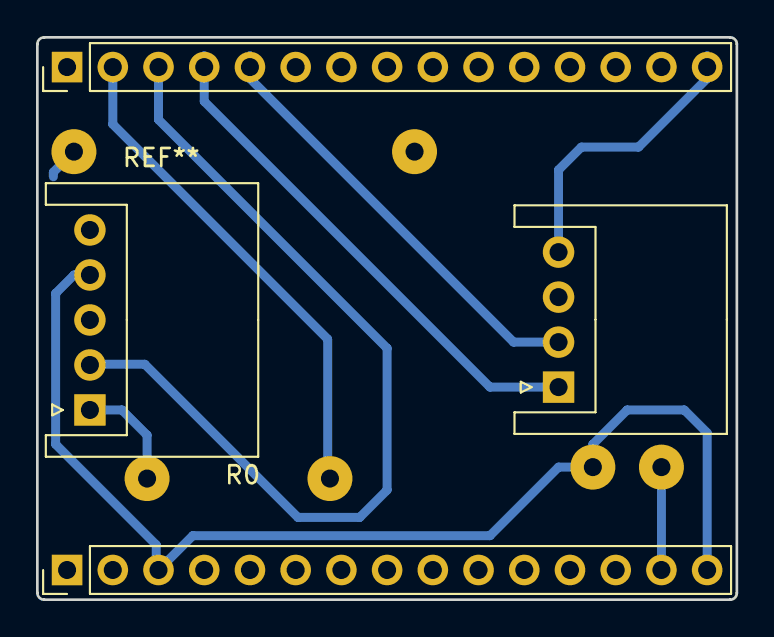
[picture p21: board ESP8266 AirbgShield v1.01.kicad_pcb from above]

Board: 2 copper layers, 38.9 x 31.2 mm, 6 parts (0 on the bottom side), 8 nets.

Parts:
J1, J2: P15; Pin_Header_Straight_1x15_Pitch2.54mm
J3: SDS011; JST_XH_S05B-XH-A_05x2.50mm_Angled
J4: BME280; JST_XH_S04B-XH-A_04x2.50mm_Angled
Power: WireConnection_1mmDrill; WireConnection_1.00mmDrill
R0: J; WireConnection_1.00mmDrill

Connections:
+3V3: J2.15, J4.4
+5V: J1.3, J1.15, J3.4, Power.1
GND: J1.14, J2.14, J3.3, J4.3, Power.2
I2C_SCL: J2.5, J4.2
I2C_SDA: J2.4, J4.1
unnamed: J2.2, R0.1
RX: J2.3, J3.2
TX: J3.1, R0.2

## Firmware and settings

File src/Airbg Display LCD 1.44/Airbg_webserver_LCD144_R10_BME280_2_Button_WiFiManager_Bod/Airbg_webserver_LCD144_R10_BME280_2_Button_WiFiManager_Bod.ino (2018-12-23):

#include <ESP8266WiFi.h>
#include <WiFiClient.h>
#include <WiFiManager.h>     //https://github.com/kentaylor/WiFiManager
#include <ESP8266WebServer.h>
#include <ESP8266mDNS.h>
#include <DNSServer.h>
#include <ArduinoJson.h>
#include <SPI.h>
#include <TFT_eSPI.h> // https://github.com/Bodmer/TFT_eSPI
#include <Wire.h>
#include <Adafruit_Sensor.h>
#include <Adafruit_BME280.h>

#define _TIMEOUT_ 1000

 //set static ip
#define STATIC_IP 192,168,0,50 
IPAddress ip(STATIC_IP);   
IPAddress gateway(192,168,0,1);   
IPAddress subnet(255,255,255,0); 
ESP8266WebServer server(80);
 // Indicates whether ESP has WiFi credentials saved from previous session.
bool initialConfig = false;
   

float t, tBME;
int p25, p10, h, p, s, id, hBME, pBME, counter = 1;
char tString[6];
char tBMEString[6];
char tTailString[6];
char tBMETailString[6];


bool status = true;

int lastCheck;

const int LED = D4; //2 Controls the onboard LED.
const int B1_PIN = D6; //12 Changing LCD pages.
const int B2_PIN = D3; //0 FLASH Button onboard, Start wifi config mode


 // Initialize the BME280 I2C
Adafruit_BME280 bme;

// Inicialize display LCD TFT 1.44" 
// Don't forget to update "User_Setup.h" in Bodmer libray for LCD pins
// ST7735_DRIVER and your type board
// TFT_WIDTH  128
// TFT_HEIGHT 128
// TFT_CS          PIN_D8
// TFT_DC          PIN_D0
// TFT_RST  -1     Reset pin on ESP8266

// D0_USED_FOR_DC  

uint16_t colorPM;


TFT_eSPI tft = TFT_eSPI();  // Invoke library


void setup(void){
  Serial.begin(115200);
  Serial.println("...");
  
   // TFT LCD Start.
  tft.init();
  tft.setRotation(0);             //0,1,2,3
  tft.fillScreen(TFT_BLACK);
  tft.setTextColor(TFT_WHITE);
  
  pinMode(LED, OUTPUT);
  digitalWrite(LED, HIGH);
  pinMode(B1_PIN, INPUT_PULLUP);
  pinMode(B2_PIN, INPUT_PULLUP);
  
  // BME280 Start.
  Wire.begin(D1, D2);
  bme.begin();
  get_BME();

  // Memory pool for JSON object tree.
  while (!Serial) continue;

  
   // Wi-Fi starting.
  WiFi.printDiag(Serial); //Remove this line if you do not want to see WiFi password printed
  if (WiFi.SSID()==""){
      Serial.println("No credentials, so get them now");
      tft.drawCentreString("No Credential,",64,25,1);
      tft.drawCentreString("So Get Them Now",64,40,1);
      tft.drawCentreString("STARTING",64,75,1);
      tft.drawCentreString("CONFIG MODE",64,90,1);
      delay(2000);      
      initialConfig = true;
   } else {
      digitalWrite(LED, HIGH);          // Turn led off as we are not in configuration mode.
      WiFi.mode(WIFI_STA);              // Force to station mode because if device was switched off while in access point mode it will start up next time in access point mode.
      WiFi.config(ip, gateway, subnet); // For static IP
      unsigned long startedAt = millis();
      Serial.print("After waiting ");
      int connRes = WiFi.waitForConnectResult();
      float waited = (millis()- startedAt);
      Serial.print(waited/1000);
      Serial.println(" secs in setup()  ");
      Serial.print("connection result is: ");
      Serial.println(connRes);
      Serial.print("IP address is: ");
      Serial.println(WiFi.localIP());
      Serial.println(".");

      tft.setTextSize(1);
      tft.drawCentreString(WiFi.SSID(),64,10,2); // (Text,X,Y,Font)
      tft.setTextFont(1);
      tft.setCursor(28, 40); tft.println(WiFi.localIP());
      tft.setCursor(30, 55); tft.print(WiFi.channel()); tft.print("ch");
      tft.setCursor(63, 55); tft.print(WiFi.RSSI()); tft.print("dbm");
      tft.drawCentreString("Waiting",64, 85,1);
      tft.drawCentreString("Sensor Data",64, 105,1);
  }

  // mDNS server starting.
  if (MDNS.begin("esp8266")) {
    Serial.println("MDNS responder started");
  }


  server.on("/", handleRoot);
  server.begin();
  Serial.println("HTTP server started");
  Serial.println("Waiting sensor data...");

  lastCheck = millis();
}

void handleRoot() {
     if (server.hasArg("plain")== false){ //Check if body received
          server.send(200, "text/plain", "Body not received");
          return;
    }
    String message = "Body received: Json file\n";
           message += server.arg("plain");
           message += "\n";
    Serial.println(message);

    // JSON buffer size
    const size_t bufferSize = JSON_ARRAY_SIZE(9) + 9*JSON_OBJECT_SIZE(2) + JSON_OBJECT_SIZE(3) + 420;
    DynamicJsonBuffer jsonBuffer(bufferSize);
   
    // JSON input string.
    String json = server.arg("plain");

    // Root of the object tree.
    JsonObject& root = jsonBuffer.parseObject(json);

    // Test if parsing succeeds.
    if (!root.success()) {
      Serial.println("parseObject() failed");
      return;
    }

    // Fetch values from Json file.
    id = atoi(root["esp8266id"]); // ESP8266 ID number
    JsonArray& sensordatavalues = root["sensordatavalues"];
    for(auto sensor : sensordatavalues){
      if(strcmp("SDS_P1", sensor["value_type"].as<const char*>()) == 0){
        p10 = atoi(sensor["value"].as<const char*>()); 
      } else if(strcmp("SDS_P2", sensor["value_type"].as<const char*>()) == 0){
        p25 = atoi(sensor["value"].as<const char*>()); 
      } else if(strcmp("BME280_temperature", sensor["value_type"].as<const char*>()) == 0){
        t = atof(sensor["value"].as<const char*>()); 
      } else if(strcmp("BME280_humidity", sensor["value_type"].as<const char*>()) == 0){
        h = atoi(sensor["value"].as<const char*>()); 
      } else if(strcmp("BME280_pressure", sensor["value_type"].as<const char*>()) == 0){
        p = atoi(sensor["value"].as<const char*>()); 
        p /= 100;
      } else if(strcmp("signal", sensor["value_type"].as<const char*>()) == 0){
        s = atoi(sensor["value"].as<const char*>()); 
      }
    }

     // Separating temperature digits to print with different size.
    dtostrf(t, 5, 1, tString);

    // Print values.
    Serial.print("ESP8266 ID: ");
    Serial.println(id);
    Serial.println(".");
    serialprintData();
    tftprintData();
            
    server.send(200, "text/plain", "OK");    
}


// Ganerate function for BME sensor
void get_BME() {
    tBME = bme.readTemperature();
    hBME = bme.readHumidity();
    pBME = bme.readPressure()/100.0F;
    
    // Separating temperature digits to print with different size.
    dtostrf(tBME, 5, 1, tBMEString);
}


// Ganerate function for serial print.
void serialprintData() {
  get_BME(); 
  Serial.println("Indoor data"); 
  Serial.print("Temperture is: ");
  Serial.println(tBME);
  Serial.print("Humidity is: ");
  Serial.println(hBME);
  Serial.print("Presure is: ");
  Serial.println(pBME);
  Serial.println(".");
  Serial.println("Outdoor data");
  Serial.print("Temperture is: ");
  Serial.println(t);
  Serial.print("Humidity is: ");
  Serial.println(h);
  Serial.print("Presure is: ");
  Serial.println(p);
  Serial.print("Dust PPM 2.5: ");
  Serial.println(p25);
  Serial.print("Dust PPM  10: ");
  Serial.println(p10);
  Serial.print("Signal is: ");
  Serial.println(s);   
  Serial.println(".");
  Serial.println("Waiting station data");
  Serial.println(".");   
}


// Ganerate function for display pages.
void tftprintData() {
  if(counter == 1){
      Page1();
  } else if(counter == 2){
      Page2();
  } else if(counter == 3){
      Page3();
  } else if(counter == 4){
      Page4();
  }
}


void Page1() {
  get_BME();
  tft.fillScreen(TFT_BLACK);
  tft.setTextColor(TFT_WHITE);
  tft.setTextFont(1);
  tft.setCursor(5, 5); tft.print("IN");
  tft.setCursor(5, 70); tft.print("OUT");
  tft.setTextSize(1);
  tft.setCursor(110, 20); tft.print("O");
  tft.setCursor(110, 85); tft.print("O");
  tft.drawRightString(String(tBMEString[0])+String(tBMEString[1])+String(tBMEString[2]),95,20,6);
  tft.drawRightString(String(tString[0])+String(tString[1])+String(tString[2]),95,85,6);
  tft.drawString(String(tBMEString[3])+String(tBMEString[4]),95,37,4);
  tft.drawString(String(tString[3])+String(tString[4]),95,103,4);
}


void Page2() {
  tft.fillScreen(TFT_BLACK);
  tft.setTextColor(TFT_WHITE);
  tft.setTextFont(1);
  tft.setCursor(5, 5); tft.print("PM 2.5");
  tft.setCursor(5, 70); tft.print("PM  10");

  if(p25 > 150 || p10 > 150) {
    colorPM = TFT_RED;
  } else if ((p25 > 50 && p25 < 150) || (p10 > 50 && p10 < 150)) {
    colorPM = TFT_ORANGE; 
  } else if(p25 < 50 || p10 < 50) {
    colorPM = TFT_WHITE;
  }
  tft.setTextFont(6);
  tft.setTextColor(colorPM);
  tft.drawRightString(String((int)p25),110,20,6);
  tft.drawRightString(String((int)p10),110,85,6);
}  


void Page3() {
  tft.fillScreen(TFT_BLACK);
  tft.setTextColor(TFT_WHITE);
  tft.setTextFont(1);
  tft.setCursor(10, 5); tft.print("OUTDOOR");
  tft.setCursor(95, 25); tft.print("O");
  tft.drawRightString(String(tString), 90, 25, 4);
  tft.setTextFont(1);
  tft.setCursor(29, 60); tft.print("HUMID: "); tft.print(h); tft.print(" %");
  tft.setCursor(17, 75); tft.print("PRESURE: "); tft.print(p); tft.print(" hPa");
  tft.setCursor(24, 100); tft.print("WiFi S: "); tft.print(s); tft.print(" dBm");
}  


void Page4() {
  get_BME();
  tft.fillScreen(TFT_BLACK);
  tft.setTextColor(TFT_WHITE);
  tft.setTextFont(1);
  tft.setCursor(10, 5); tft.print("INDOOR");
  tft.setCursor(95, 25); tft.print("O");
  tft.drawRightString(String(tBMEString), 90, 25, 4);
  tft.setTextFont(1);
  tft.setCursor(29, 60); tft.print("HUMID: "); tft.print(hBME); tft.print(" %");
  tft.setCursor(17, 75); tft.print("PRESURE: "); tft.print(pBME); tft.print(" hPa");
  tft.setCursor(28, 100); tft.print(WiFi.localIP());
  tft.setCursor(28, 115); tft.print(WiFi.channel()); tft.print("ch");
  tft.setCursor(64, 115); tft.print(WiFi.RSSI()); tft.print("dBm");
}


 // Display LCD page for config mode.
void configModeCallback (WiFiManager *myWiFiManager) {
  tft.fillScreen(TFT_BLACK);
  tft.setTextColor(TFT_WHITE);
  tft.setTextFont(1);
  tft.drawCentreString("CONFIG MODE",64, 25, 1);
  tft.drawCentreString("START:",64, 40, 1);
  tft.setCursor(35, 75); tft.print(myWiFiManager->getConfigPortalSSID());
  delay(100);
  tft.setCursor(32, 90); tft.print(WiFi.softAPIP());
}


void loop(void){
  
    // If configuration portal requested?
  if ((digitalRead(B2_PIN) == LOW) || (initialConfig)) {
    server.close(); //Stop previous server
    Serial.println("Configuration portal requested.");
    digitalWrite(LED, LOW);
    WiFiManager wifiManager;
    
    //reset settings - for testing
    //wifiManager.resetSettings();
   
    wifiManager.setAPCallback(configModeCallback);
    if (!wifiManager.startConfigPortal()) {
      Serial.println("Not connected to WiFi but continuing anyway.");
    } else {
      Serial.println("Connected to WiFi.");
    }
     digitalWrite(LED, HIGH);
     Serial.println("WM: Reset ESP"); 
     ESP.reset();
     delay(5000);  
  }
  
    // Reset of ESP if wrong IP address.
  if(WiFi.localIP() == IPAddress(STATIC_IP)) {
    server.handleClient();    
  } else {
    Serial.println(".");
    Serial.println("Wrong IP: Reset ESP");
    ESP.reset();
    delay(1000);
  }  

  //if(id != 0){                       // When receive ESP ID from sensor
     if(digitalRead(B1_PIN) == LOW){   // LCD display pages changing with button 1
      if(counter >= 4){                //Number of pages
        counter = 1;
      } else {
        counter++;
      }
      Serial.println(".");
      Serial.print("LCD page ");
      Serial.println(counter);
      tftprintData();
      delay(200);        
    }
   //}
  
   // Status of ESP8266
  if(millis() - lastCheck > _TIMEOUT_){
    if(status){
      digitalWrite(LED, LOW);  //turn on diode
      status = false;
    } else {
      digitalWrite(LED, HIGH); //turn off diode
      status = true;
    }
    lastCheck = millis();
  }
}

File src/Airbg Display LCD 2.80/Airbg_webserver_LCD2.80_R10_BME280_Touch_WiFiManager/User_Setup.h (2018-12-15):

//                            USER DEFINED SETTINGS
//   Set driver type, fonts to be loaded, pins used and SPI control method etc
//
//   See the User_Setup_Select.h file if you wish to be able to define multiple
//   setups and then easily select which setup file is used by the compiler.
//
//   If this file is edited correctly then all the library example sketches should
//   run without the need to make any more changes for a particular hardware setup!
//   Note that some sketches are designed for a particular TFT pixel width/height

// ##################################################################################
//
// Section 0. Call up the right driver file and any options for it
//
// ##################################################################################

// Only define one driver, the other ones must be commented out
#define ILI9341_DRIVER
//#define ST7735_DRIVER
//#define ILI9163_DRIVER
//#define S6D02A1_DRIVER
//#define RPI_ILI9486_DRIVER // 20MHz maximum SPI
//#define HX8357D_DRIVER
//#define ILI9481_DRIVER
//#define ILI9488_DRIVER

// For M5Stack ESP32 module with integrated display ONLY, remove // in line below
//#define M5STACK

// For ST7735  and ILI9163 ONLY, define the pixel width and height in portrait orientation
//#define TFT_WIDTH  128
//#define TFT_HEIGHT 160
//#define TFT_HEIGHT 128

// For ST7735 ONLY, define the type of display, originally this was based on the
// colour of the tab on the screen protector film but this is not always true, so try
// out the different options below if the screen does not display graphics correctly,
// e.g. colours wrong, mirror images, or tray pixels at the edges.
// Comment out ALL BUT ONE of these options for a ST7735 display driver, save this
// this User_Setup file, then rebuild and upload the sketch to the board again:

//#define ST7735_INITB
//#define ST7735_GREENTAB
//#define ST7735_GREENTAB2
//#define ST7735_GREENTAB3
//#define ST7735_GREENTAB128 // For 128 x 128 display
//#define ST7735_REDTAB
//#define ST7735_BLACKTAB

// ##################################################################################
//
// Section 1. Define the pins that are used to interface with the display here
//
// ##################################################################################

// We must use hardware SPI, a minimum of 3 GPIO pins is needed.
// Typical setup for ESP8266 NodeMCU ESP-12 is :
//
// Display SDO/MISO  to NodeMCU pin D6 (or leave disconnected if not reading TFT)
// Display LED       to NodeMCU pin VIN (or 5V, see below)
// Display SCK       to NodeMCU pin D5
// Display SDI/MOSI  to NodeMCU pin D7
// Display DC (RS/AO)to NodeMCU pin D3
// Display RESET     to NodeMCU pin D4 (or RST, see below)
// Display CS        to NodeMCU pin D8 (or GND, see below)
// Display GND       to NodeMCU pin GND (0V)
// Display VCC       to NodeMCU 5V or 3.3V
//
// The TFT RESET pin can be connected to the NodeMCU RST pin or 3.3V to free up a control pin
//
// The DC (Data Command) pin may be labeled AO or RS (Register Select)
//
// With some displays such as the ILI9341 the TFT CS pin can be connected to GND if no more
// SPI devices (e.g. an SD Card) are connected, in this case comment out the #define TFT_CS
// line below so it is NOT defined. Other displays such at the ST7735 require the TFT CS pin
// to be toggled during setup, so in these cases the TFT_CS line must be defined and connected.
//
// The NodeMCU D0 pin can be used for RST
//
// See Section 2. below if DC or CS is connected to D0
//
// Note: only some versions of the NodeMCU provide the USB 5V on the VIN pin
// If 5V is not available at a pin you can use 3.3V but backlight brightness
// will be lower.


// ###### EDIT THE PIN NUMBERS IN THE LINES FOLLOWING TO SUIT YOUR ESP8266 SETUP ######

// For NodeMCU - use pin numbers in the form PIN_Dx where Dx is the NodeMCU pin designation
#define TFT_CS   PIN_D8  // Chip select control pin D8
#define TFT_DC   PIN_D0  // Data Command control pin
//#define TFT_RST  PIN_D4  // Reset pin (could connect to NodeMCU RST, see next line)
#define TFT_RST  -1  // Set TFT_RST to -1 if the display RESET is connected to NodeMCU RST or 3.3V

#define TOUCH_CS PIN_D2     // Chip select pin (T_CS) of touch screen

//#define TFT_WR PIN_D2       // Write strobe for modified Raspberry Pi TFT only


// ######  FOR ESP8266 OVERLAP MODE EDIT THE PIN NUMBERS IN THE FOLLOWING LINES  ######

// Overlap mode shares the ESP8266 FLASH SPI bus with the TFT so has a performance impact
// but saves pins for other functions.
// Use NodeMCU SD0=MISO, SD1=MOSI, CLK=SCLK to connect to TFT in overlap mode

// In ESP8266 overlap mode the TFT chip select MUST connect to pin D3
//#define TFT_CS   PIN_D3
//#define TFT_DC   PIN_D5  // Data Command control pin
//#define TFT_RST  PIN_D4  // Reset pin (could connect to NodeMCU RST, see next line)
//#define TFT_RST  -1  // Set TFT_RST to -1 if the display RESET is connected to NodeMCU RST or 3.3V

// In ESP8266 overlap mode the following must be defined
//#define TFT_SPI_OVERLAP

// ###### EDIT THE PIN NUMBERS IN THE LINES FOLLOWING TO SUIT YOUR ESP32 SETUP   ######

// For ESP32 Dev board (only tested with ILI9341 display)
// The hardware SPI can be mapped to any pins

//#define TFT_MISO 19
//#define TFT_MOSI 23
//#define TFT_SCLK 18
//#define TFT_CS    15  // Chip select control pin
//#define TFT_DC    2  // Data Command control pin
//#define TFT_RST   4  // Reset pin (could connect to RST pin)
//#define TFT_RST  -1  // Set TFT_RST to -1 if display RESET is connected to ESP32 board RST

// For the M5Stack module use these #define lines
//#define TFT_MISO 19
//#define TFT_MOSI 23
//#define TFT_SCLK 18
//#define TFT_CS   14  // Chip select control pin
//#define TFT_DC   27  // Data Command control pin
//#define TFT_RST  33  // Reset pin (could connect to Arduino RESET pin)
//#define TFT_BL   32  // LED back-light

//#define TOUCH_CS 21     // Chip select pin (T_CS) of touch screen

//#define TFT_WR 22    // Write strobe for modified Raspberry Pi TFT only

// ######       EDIT THE PINs BELOW TO SUIT YOUR ESP32 PARALLEL TFT SETUP        ######

// The library supports 8 bit parallel TFTs with the ESP32, the pin
// selection below is compatible with ESP32 boards in UNO format.
// Wemos D32 boards need to be modified, see diagram in Tools folder.
// Only ILI9481 and ILI9341 based displays have been tested!

// Parallel bus is only supported on ESP32
// Uncomment line below to use ESP32 Parallel interface instead of SPI

//#define ESP32_PARALLEL

// The ESP32 and TFT the pins used for testing are:
//#define TFT_CS   33  // Chip select control pin (library pulls permanently low
//#define TFT_DC   15  // Data Command control pin - use a pin in the range 0-31
//#define TFT_RST  32  // Reset pin, toggles on startup

//#define TFT_WR    4  // Write strobe control pin - use a pin in the range 0-31
//#define TFT_RD    2  // Read strobe control pin  - use a pin in the range 0-31
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

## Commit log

2018-04-02 Added code and shields
    [ESP8266 AirbgShield v1.01.kicad_pcb, ESP8266 AirbgShield v1.01.sch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]
2018-04-06 Add schematic
2018-04-06 Change folders
    [ESP8266 AirbgShield v1.01.kicad_pcb, ESP8266 AirbgShield v1.01.sch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]
2018-04-06 Add pictures
    [ESP8266 AirbgShield v1.01.kicad_pcb, ESP8266 AirbgShield v1.01.sch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]
2018-04-06 Add schematics
2018-04-08 Add Oled shield
    [NodeMCU v3 Air Shield v1.1.kicad_pcb, NodeMCU v3 Air Shield v1.1.sch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]
2018-04-29 I2C fix
2018-12-12 Some fixes
    [NodeMCU v3 AirbgDisplay V1.0 LCD1.44 BME280.kicad_pcb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]
2018-12-15 New pcb and code
    [ESP-12E AirbgDisplay V1.0 LCD2.80 BME280.kicad_pcb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]
2018-12-21 Gerber files add
    [NodeMCU v3 AirbgDisplay V1.0 LCD2.80 BME280-B.Cu.gbr, NodeMCU v3 AirbgDisplay V1.0 LCD2.80 BME280-B.Mask.gbr, NodeMCU v3 AirbgDisplay V1.0 LCD2.80 BME280-Edge.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]
